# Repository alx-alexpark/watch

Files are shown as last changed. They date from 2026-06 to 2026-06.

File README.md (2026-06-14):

# GPS-Synchronized Watch
A nRF52840-based smartwatch that synchronizes its time from GPS satelites, featuring a waterproof enclosure and month-long battery life.

## Why I made this
Commonly used time synchronization methods such as NTP commonly used by smartwatches only provide accuracy of around 5-50ms, which is honestly not that good. GPS time is accurate to 10-50 nanoseconds, which is very good. I also care a lot about privacy so I wanted to make an air-gapped smartwatch that still is able to get very accurate time.

## Design files
[View PCB/Schematics on KiCanvas](https://kicanvas.org/?repo=https%3A%2F%2Fgithub.com%2Falx-alexpark%2Fwatch%2Ftree%2Fmain%2Fpcb) \
[View CAD on OnShape](https://cad.onshape.com/documents/4c7ff3da2943e425ef5063a9/w/a0d315951a28c31d027d9c75/e/9f56870fde0bf2563f4cad87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)

## BOM
| Value | Qty | Link |
|---|-----|---|
| DSGP.1575.18.4.A.02 | 1 | [Digikey](https://www.digikey.com/en/products/detail/taoglas-limited/DSGP-1575-18-4-A-02/8275269) |
| Adafruit Wireless Chg Module | 1 | [Digikey](https://www.adafruit.com/product/1901) |
| 100nF | 9 | [C1525](https://www.lcsc.com/product-detail/C1525.html) |
| 100pF | 1 | [C1546](https://www.lcsc.com/product-detail/C1546.html) |
| 12pF | 2 | [C1547](https://www.lcsc.com/product-detail/C1547.html) |
| 47nF | 1 | [C1622](https://www.lcsc.com/product-detail/C1622.html) |
| red | 1 | [C2286](https://www.lcsc.com/product-detail/C2286.html) |
| green | 1 | [C2297](https://www.lcsc.com/product-detail/C2297.html) |
| USBLC6-2SC6 | 1 | [C7519](https://www.lcsc.com/product-detail/C7519.html) |
| 4.7uF | 5 | [C19666](https://www.lcsc.com/product-detail/C19666.html) |
| 1.13k | 1 | [C22833](https://www.lcsc.com/product-detail/C22833.html) |
| nRF52840 | 1 | [C23186](https://www.lcsc.com/product-detail/C23186.html) |
| 100k | 1 | [C25741](https://www.lcsc.com/product-detail/C25741.html) |
| 10k | 3 | [C25744](https://www.lcsc.com/product-detail/C25744.html) |
| 1.5k | 4 | [C25867](https://www.lcsc.com/product-detail/C25867.html) |
| 22uF | 1 | [C45783](https://www.lcsc.com/product-detail/C45783.html) |
| 1uF | 5 | [C52923](https://www.lcsc.com/product-detail/C52923.html) |
| BQ24074RGT | 1 | [C54313](https://www.lcsc.com/product-detail/C54313.html) |
| RV-3028-C7 | 1 | [C3019759](https://www.lcsc.com/product-detail/C3019759.html) |
| 1A/1.8A | 1 | [C70082](https://www.lcsc.com/product-detail/C70082.html) |
| 10uH | 2 | [C88182](https://www.lcsc.com/product-detail/C88182.html) |
| 10uF | 1 | [C96446](https://www.lcsc.com/product-detail/C96446.html) |
| 15nH | 1 | [C98055](https://www.lcsc.com/product-detail/C98055.html) |
|  | 1 | [C127355](https://www.lcsc.com/product-detail/C127355.html) |
| LiPo (JST-PH Connector) | 1 | [C295747](https://www.lcsc.com/product-detail/C295747.html) |
| TPS63802DLAR | 1 | [C2845237](https://www.lcsc.com/product-detail/C2845237.html) |
| 91k | 1 | [C2906973](https://www.lcsc.com/product-detail/C2906973.html) |
| 4.12k | 2 | [C2930007](https://www.lcsc.com/product-detail/C2930007.html) |
| 511k | 1 | [C2930114](https://www.lcsc.com/product-detail/C2930114.html) |
| USB_C_Receptacle_USB2.0_14P | 1 | [C2988369](https://www.lcsc.com/product-detail/C2988369.html) |
| 1.18k | 1 | [C3016052](https://www.lcsc.com/product-detail/C3016052.html) |
| TPS2116DRL | 1 | [C3235557](https://www.lcsc.com/product-detail/C3235557.html) |
| MAX-M10S | 1 | [C4153167](https://www.lcsc.com/product-detail/C4153167.html) |
| 46.4k | 1 | [C5126026](https://www.lcsc.com/product-detail/C5126026.html) |
| 32MHz | 1 | [C5441424](https://www.lcsc.com/product-detail/C5441424.html) |
| 0.47uH | 1 | [C18221164](https://www.lcsc.com/product-detail/C18221164.html) |
| TPS7A20xxxDQN | 1 | [C46459900](https://www.lcsc.com/product-detail/C46459900.html) |

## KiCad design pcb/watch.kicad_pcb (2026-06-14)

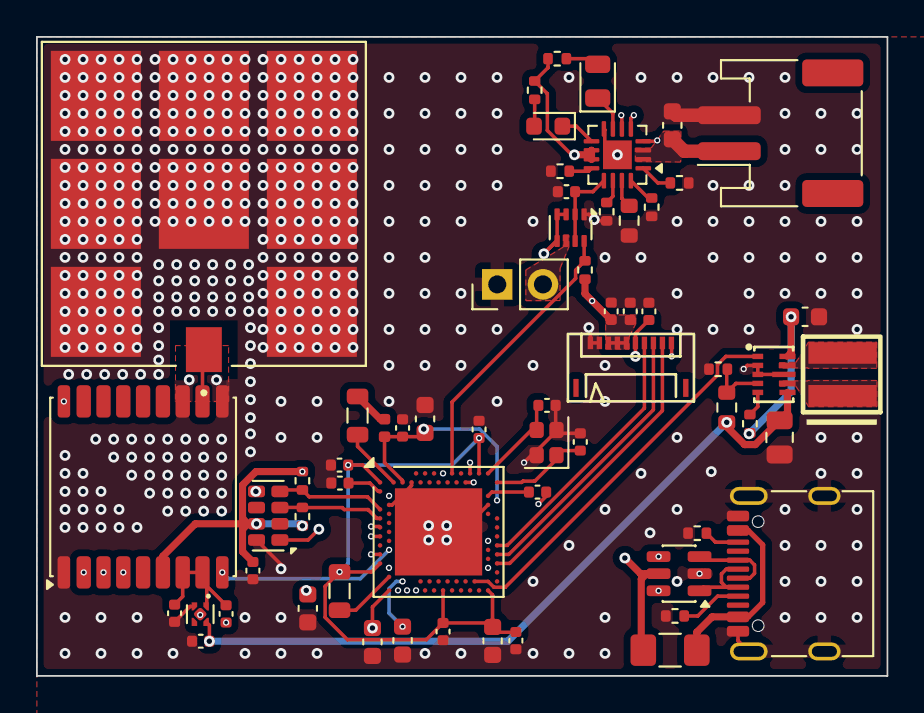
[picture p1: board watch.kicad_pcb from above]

Board: 6 copper layers, 47.2 x 35.5 mm, 61 parts (0 on the bottom side), 59 nets.

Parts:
BT1: LiPo; JST_PH_S2B-PH-SM4-TB_1x02-1MP_P2.00mm_Horizontal
C1, C6, C7, C8, C9, C15, C25, C27, C28: 100nF; C_0402_1005Metric
C2, C10, C11, C12, C22: 4.7uF; C_0603_1608Metric
C3, C4: 12pF; C_0402_1005Metric
C5: 100pF; C_0402_1005Metric
C13, C18, C19, C21, C26: 1uF; C_0402_1005Metric
C14: 47nF; C_0603_1608Metric
C17: 10uF; C_0603_1608Metric
C20: 22uF; C_0805_2012Metric
D1: green; LED_0805_2012Metric
D2: red; LED_0603_1608Metric
DS1: 5034801000
E1: DSGP.1575.18.4.A.02; XCVR_DSGP.1575.18.4.A.02
F1: 1A/1.8A; Fuse_1206_3216Metric_Pad1.42x1.75mm_HandSolder
J1: USB_C_Receptacle_USB2.0_14P; USB_C_Receptacle_G-Switch_GT-USB-7010ASV
J2: Adafruit Wireless Chg Module; PinHeader_1x02_P2.54mm_Vertical
L1, L2: 10uH; L_0805_2012Metric
L3: 15nH; L_0402_1005Metric
L4: 0.47uH; XFL4015-471MEC
R1, R2: 4.12k; R_0402_1005Metric
R3: 511k; R_0603_1608Metric
R4: 91k; R_0402_1005Metric
R5: 100k; R_0402_1005Metric
R6: 1.18k; R_0402_1005Metric
R7, R8, R11, R12: 1.5k; R_0402_1005Metric
R9: 1.13k; R_0603_1608Metric
R10: 46.4k; R_0402_1005Metric
R15, R16, R17: 10k; R_0402_1005Metric
U1: nRF52840; Nordic_AQFN-73-1EP_7x7mm_P0.5mm
U2: USBLC6-2SC6; SOT-23-6
U3: MAX-M10S; ublox_MAX
U4: TPS63802DLAR
U5: TPS7A20xxxDQN; Texas_X2SON-4_1x1mm_P0.65mm
U6: BQ24074RGT; VQFN-16-1EP_3x3mm_P0.5mm_EP1.6x1.6mm
U8: RV-3028-C7; MicroCrystal_C7_SON-8_1.5x3.2mm_P0.9mm
U9: TPS2116DRL; SOT-583-8
Y1: 32MHz; Crystal_SMD_2016-4Pin_2.0x1.6mm

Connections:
+3V0_GPS: C15.1, C19.1, U3.7 (VCC_IO), U3.8 (VCC), U5.1 (OUT)
+3V3: C26.1, C27.1, C28.1, DS1.3 (EXTMODE), DS1.4 (VDD), DS1.5 (VDDA), R15.1, R16.1, R17.1, U3.6 (V_BCKP), U8.7 (VDD)
+3V3_ALT: C18.1, C20.1, R3.1, U4.6 (VOUT), U5.4 (IN)
+BATT: C11.1, C17.1, R5.1, R11.2, R12.2, U1.Y2 (VDDH), U4.10 (VIN), U6.10 (OUT), U6.11 (OUT)
/mcu/D+: U1.AD6 (D+), U2.4 (I/O2)
/mcu/D-: U1.AD4 (D-), U2.6 (I/O1)
/mcu/DEC4: C13.1, C14.1, L3.1, U1.B5 (DEC4), U1.E24 (DEC6)
/mcu/VDD_nRF: C1.1, C6.1, C8.1, C9.1, C10.1, L1.1, U1.A22 (VDD), U1.AD14 (VDD), U1.AD23 (VDD), U1.B1 (VDD), U1.W1 (VDD)
GND: BT1.2 (-), C1.2, C2.2, C3.1, C4.1, C5.2, C6.2, C7.2, C8.2, C9.2, C10.2, C11.2, C12.2, C13.2, C14.2, C15.2, C17.2, C18.2, C20.2, C21.2, C22.2, C25.2, C26.2, C27.2, C28.2, DS1.1 (VSSA), DS1.2 (VSS), E1.2, E1.3, E1.4, E1.5, E1.6, E1.7, E1.8, E1.9, J1.A1 (GND), J1.A12 (GND), J1.B1 (GND), J1.B12 (GND), J1.SH (SHIELD), J2.1, R1.2, R2.2, R4.2, R6.1, R7.1, R8.1, R9.1, R10.2, U1.B7 (VSS), U1.EP (VSS), U1.F2 (XL2/P0.01), U1.F23 (VSS_PA), U2.2 (GND), U3.1 (GND), U3.10 (GND), U3.12 (GND), U4.2 (MODE), U4.3 (AGND), U4.8 (GND), U5.2 (GND), U6.8 (VSS), U6.17 (VSS), U8.5 (VSS), U8.8 (EVI), U9.1 (GND), Y1.2 (G), Y1.4 (G)
LF_EXT_CLK: U1.D2 (XL1/P0.00), U8.1 (CLKOUT)
unnamed: BT1.1 (+), C22.1, U6.2 (BAT), U6.3 (BAT)
unnamed: C19.2, U5.5 (Pad)
unnamed: D1.2 (A), R11.1
unnamed: D1.1 (K), U6.7 (~PGOOD)
unnamed: D2.2 (A), R12.1
unnamed: D2.1 (K), U6.9 (~CHG)
unnamed: F1.1, J1.A4 (VBUS), J1.A9 (VBUS), J1.B4 (VBUS), J1.B9 (VBUS)
unnamed: J1.A5 (CC1), R1.1
unnamed: J1.B5 (CC2), R2.1
unnamed: J1.A6 (D+), J1.B6 (D+), U2.3 (I/O2)
unnamed: J1.A7 (D-), J1.B7 (D-), U2.1 (I/O1)
unnamed: J2.2, U9.6 (VIN2)
unnamed: L2.1, L3.2
unnamed: L2.2, U1.B3 (DCC)
unnamed: L1.2, U1.AB2 (DCCH)
unnamed: C7.1, U1.C1 (DEC1)
unnamed: C5.1, U1.D23 (DEC3)
unnamed: C2.1, U1.AC5 (DECUSB)
unnamed: C3.2, U1.B24 (XC1), Y1.1
unnamed: C4.2, U1.A23 (XC2), Y1.3
unnamed: E1.1, U3.11 (RF_IN)
unnamed: R3.2, R4.1, U4.4 (FB)
unnamed: L4.2, U4.9 (L1)
unnamed: L4.1, U4.7 (L2)
unnamed: R5.2, U4.5 (PG)
unnamed: R7.2, U6.12 (ILIM)
unnamed: R8.2, U6.16 (ISET)
unnamed: R9.2, U6.15 (ITERM)
unnamed: R6.2, U6.14 (TMR)
unnamed: R10.1, U6.1 (TS)
P0.04: R15.2, U1.J1 (AIN2/P0.04), U8.3 (SCL)
P0.06: U1.L1 (P0.06), U3.18 (~SAFEBOOT)
P0.08: U1.N1 (P0.08), U3.2 (TXD)
P0.11: U1.T2 (TRACEDATA2/P0.11), U3.9 (~RESET)
P0.12: U1.U1 (TRACEDATA1/P0.12), U3.3 (RXD)
P0.25: U1.AC21 (P0.25), U4.1 (EN)
P0.26: R16.2, U1.G1 (P0.26), U8.4 (SDA)
P1.01: DS1.10 (SCLK), U1.Y23 (P1.01)
P1.02: DS1.9 (SI), U1.W24 (P1.02)
P1.04: DS1.8 (SCS), U1.U24 (P1.04)
P1.06: DS1.7 (EXTCOMIN), U1.R24 (P1.06)
P1.07: C25.1, DS1.6 (DISP), U1.P23 (P1.07)
P1.10: U1.A20 (P1.10), U6.5 (EN2)
P1.11: U1.B19 (P1.11), U6.4 (~CE)
P1.13: R17.2, U1.A16 (P1.13), U9.8 (ST)
P1.15: U1.A14 (P1.15), U6.6 (EN1)
TIMEPULSE: U1.AD8 (P0.13), U3.4 (TIMEPULSE)
VBUS: C12.1, F1.2, U1.AD2 (VBUS), U2.5 (VBUS), U9.3 (VIN1), U9.4 (PR1), U9.5 (MODE)
V_CHARGE: C21.1, U6.13 (IN), U9.2 (VOUT), U9.7 (VOUT)

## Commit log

2026-06-05 sus commit
    [display.kicad_sch, pwr.kicad_sch, rtc.kicad_sch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]
2026-06-05 fix symbols getting absolutely goofed up
    [gps.kicad_sch, oled.kicad_sch, pwr.kicad_sch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]
2026-06-05 del oled.sch
    [oled.kicad_sch]
2026-06-05 fix more stuffies
    [display.kicad_sch, gps.kicad_sch, pwr.kicad_sch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]
2026-06-05 ALMOST done with parts purgatory
    [gps.kicad_sch, pwr.kicad_sch, watch.kicad_sch]
2026-06-07 done for the day
    [watch.kicad_pcb]
2026-06-08 change to 4layer
    [watch.kicad_pcb]
2026-06-10 starting le leyout
    [gps.kicad_sch, pwr.kicad_sch, watch.kicad_pcb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]
2026-06-13 almost done?
    [gps.kicad_sch, watch.kicad_pcb]
